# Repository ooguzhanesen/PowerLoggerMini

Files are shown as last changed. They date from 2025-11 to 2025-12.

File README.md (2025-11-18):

# Mini Power Logger

> **Hazırlayan:** Oğuzhan ESEN  
> **Proje Adı:** Mini Power Logger
> **Tarih:** 11 Kasım 2025
> **Versiyon:** v1.0
---

## İçindekiler

---

## 1. Giriş

Mini Power Logger, gerilim, akım ve güç tüketimini ölçmek, bu verileri hafızaya kaydetmek ve ekran üzerinden anlık olarak göstermek amacıyla geliştirilmiş bir izleme kartıdır.

Sistem, STM32F103 mikrodenetleyici tabanlıdır ve INA228 yüksek çözünürlüklü akım–voltaj sensörü sayesinde 20 bit çözünürlükte hassas ölçüm yapabilmektedir. Ayrıca  ölçülen veriler microSD karta kaydedebilmekte ve aynı zamanda OLED ekranda anlık değerler görülebilmektedir.

Mini Power Logger, arge projelerinde üzeritilen prototip ve cihazların güç tüketimini incelemek amacıyla tasarlanmıştır.

---

## 2. Tasarımın Amacı ve Kapsamı

Bu tasarımın temel amacı, enerji tüketimini düşük maliyetle, taşınabilir bir sistem üzerinden izleyebilmek ve ölçüm sonuçlarını kolayca kayıt altına almaktır.
Mini Power Logger, aşağıdaki fonksiyonları yerine getirir:

* 7–28 V DC aralığında güç girişi

* INA228 sensörü ile akım ve voltaj ölçümü (3 A'e kadar)

* microSD kart üzerinden veri kaydı

* 0.96” OLED ekran ile anlık ölçüm gösterimi

* USB Type-C bağlantısı (alternatif besleme ve veri aktarımı)

* 2 adet sıcaklık sensörü (cihazın çeşitli konumlarında sıcaklık ölçümü alabilmek için)

* 3 adet buton (menü kontrolü ve fonksiyon seçimi)

* Buzzer ile sesli uyarı

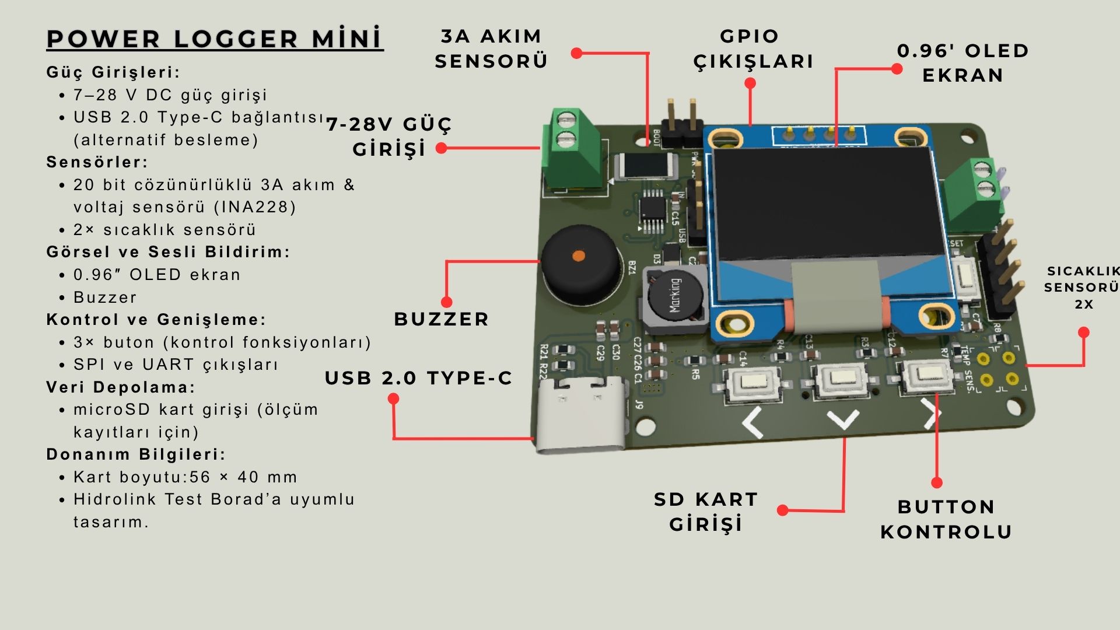
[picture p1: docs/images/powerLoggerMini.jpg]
Tanıtım Gorseli

---

## 3. Sistem Blok Diyagramı

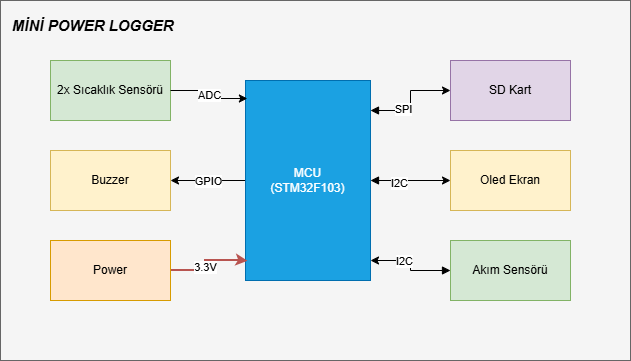
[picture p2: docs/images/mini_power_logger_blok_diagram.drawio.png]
Block Diagram


---

## 4. Şematik ve PCB
[Şematik tasarım için tıklayın.](docs/mini_power_logger.pdf)

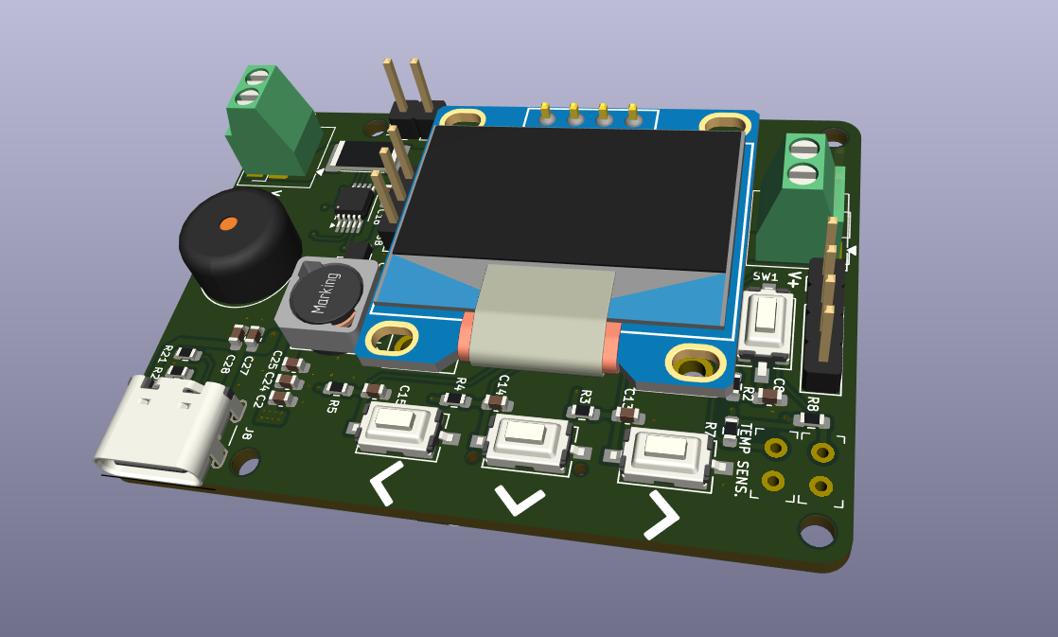
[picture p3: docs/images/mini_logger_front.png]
Mini Logger Front


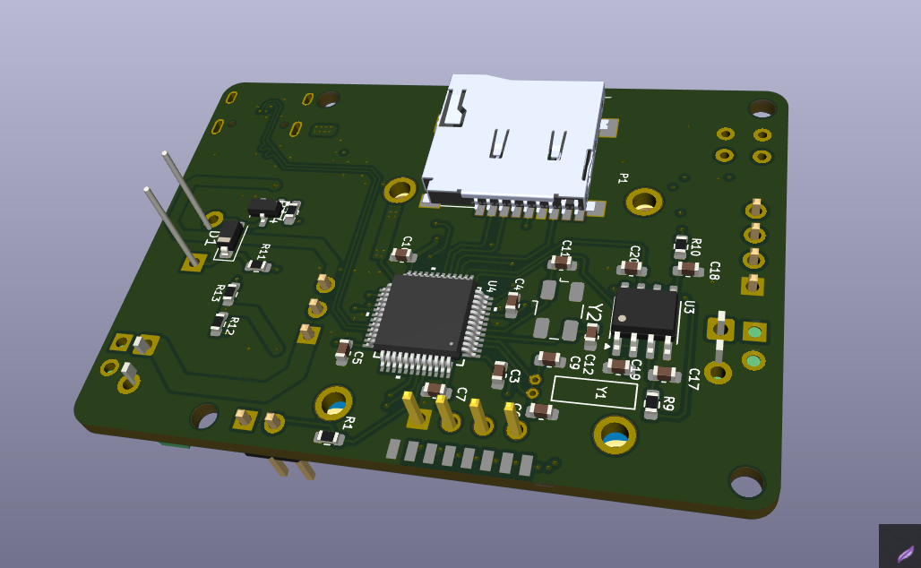
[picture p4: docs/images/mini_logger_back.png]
Mini Logger back


---

## 5. Test Notları

---

## 6. Geliştirme ve İyileştirme Önerileri

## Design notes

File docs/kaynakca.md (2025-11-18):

# Power Logger Mini Yazılım klavuzu 

> **Hazırlayan:** Oğuzhan ESEN  
> **Proje Adı:** STM32WL Nucleo Carrier Board  
> **Tarih:** 22 ekim 2025  
> **Versiyon:** v1.0

---

## 1. Giriş

Power Logger Mini porjesinde şu özelliklerin olması planlanmıştır.
- Akım ve voltaj bilgisinin edinilmesi (INA219,226,228).
- Oled ekran üzerinden gösterilmesi.
- Verileri sd karta kaydetmesi.
- Buton ile kayıt kontrolünün yapılması.
- Kaydın yapılırken tarih saat bilgisinin alınması.
- Hidrolink Test Boarda uyumlu olması.

Bu özellikleri karşılayabilmesi için komponet seçimi ve kaynakları verilmiştir.

### 1.1 Akım Voltaj bilgisinin karşılanması  için:
Bu bilginin karşılanması amacıyla INA219 , INA226 denenmiştir. INA226 bir ölçüde uygun oldugu görülmiş ama 16bit çözünürlük yerine 20 bit çözünürlüğün daha iyi olacagı
öngörüldüğü için INA228 kullanılmasına karar verilmiştir.
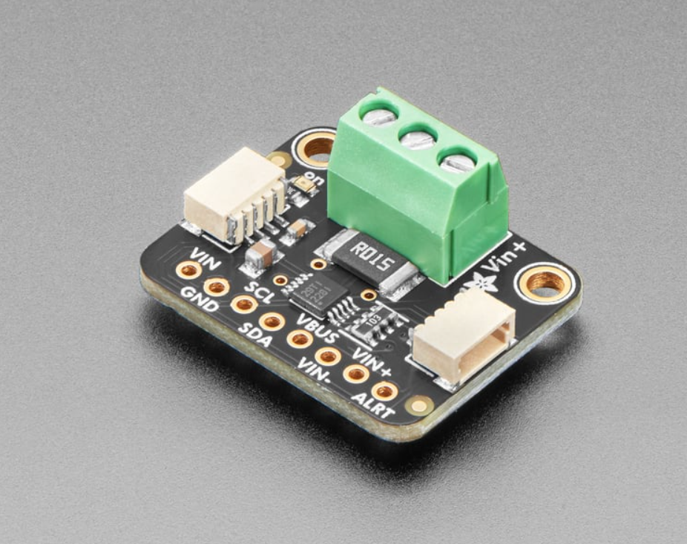
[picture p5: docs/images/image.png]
ına226


[INA228](https://www.ozdisan.com/p/diger-guc-yonetimi-entegreleri-281/texas-ina228aqdgsrq1-1086895)
[Arduino libi](https://github.com/RobTillaart/INA228)
[Sematik ve tasarım dosyaları](https://github.com/adafruit/Adafruit-INA228-PCB)

### 1.2 OLED Ekran:
Biglerin gösterimi için i2c ile çalışan oled ekran seçilmiştir.
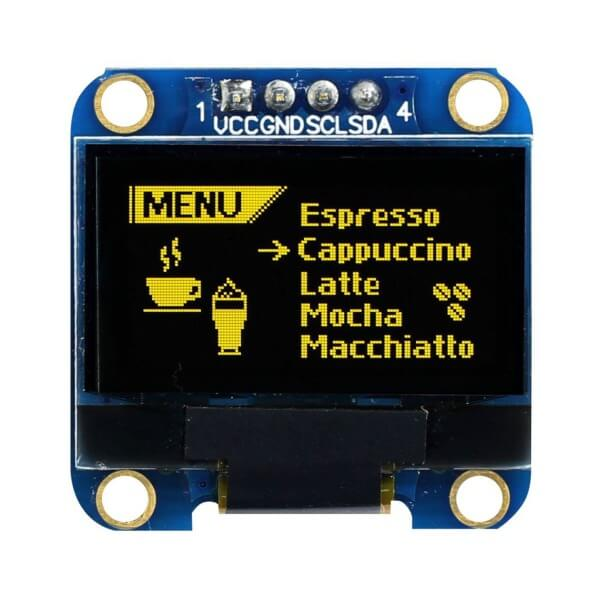
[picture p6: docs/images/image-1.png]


[Kullanılan ekranın datasheet'i](https://www.ozdisan.com/api/pdf/product/assets/WEA012864DLPP3N00003.pdf)

[Test için kullandığım git linki](https://github.com/RobertoBenjami/stm32_ssd1306_i2c_dma_hal/tree/master/Drivers)

### 1.3 SD Card:
SD kartta modülü kullanılmıştır ve sd karta kayıt spi üzerinden yapılmaktadır.
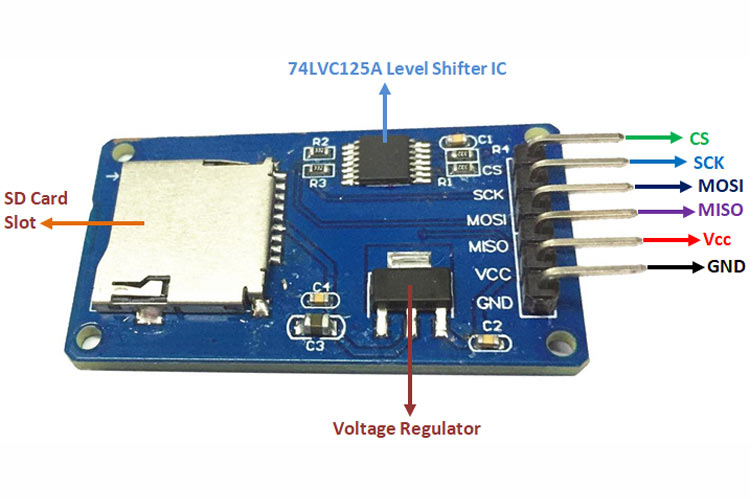
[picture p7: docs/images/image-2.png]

[SD kart için kullanılan kaynak](https://youtu.be/PBIm8BCnbyQ)
[SD kart için kullanılan git linki](https://github.com/PRTechTalk/STM32/tree/main/SD_Card_SPI_FatFs)

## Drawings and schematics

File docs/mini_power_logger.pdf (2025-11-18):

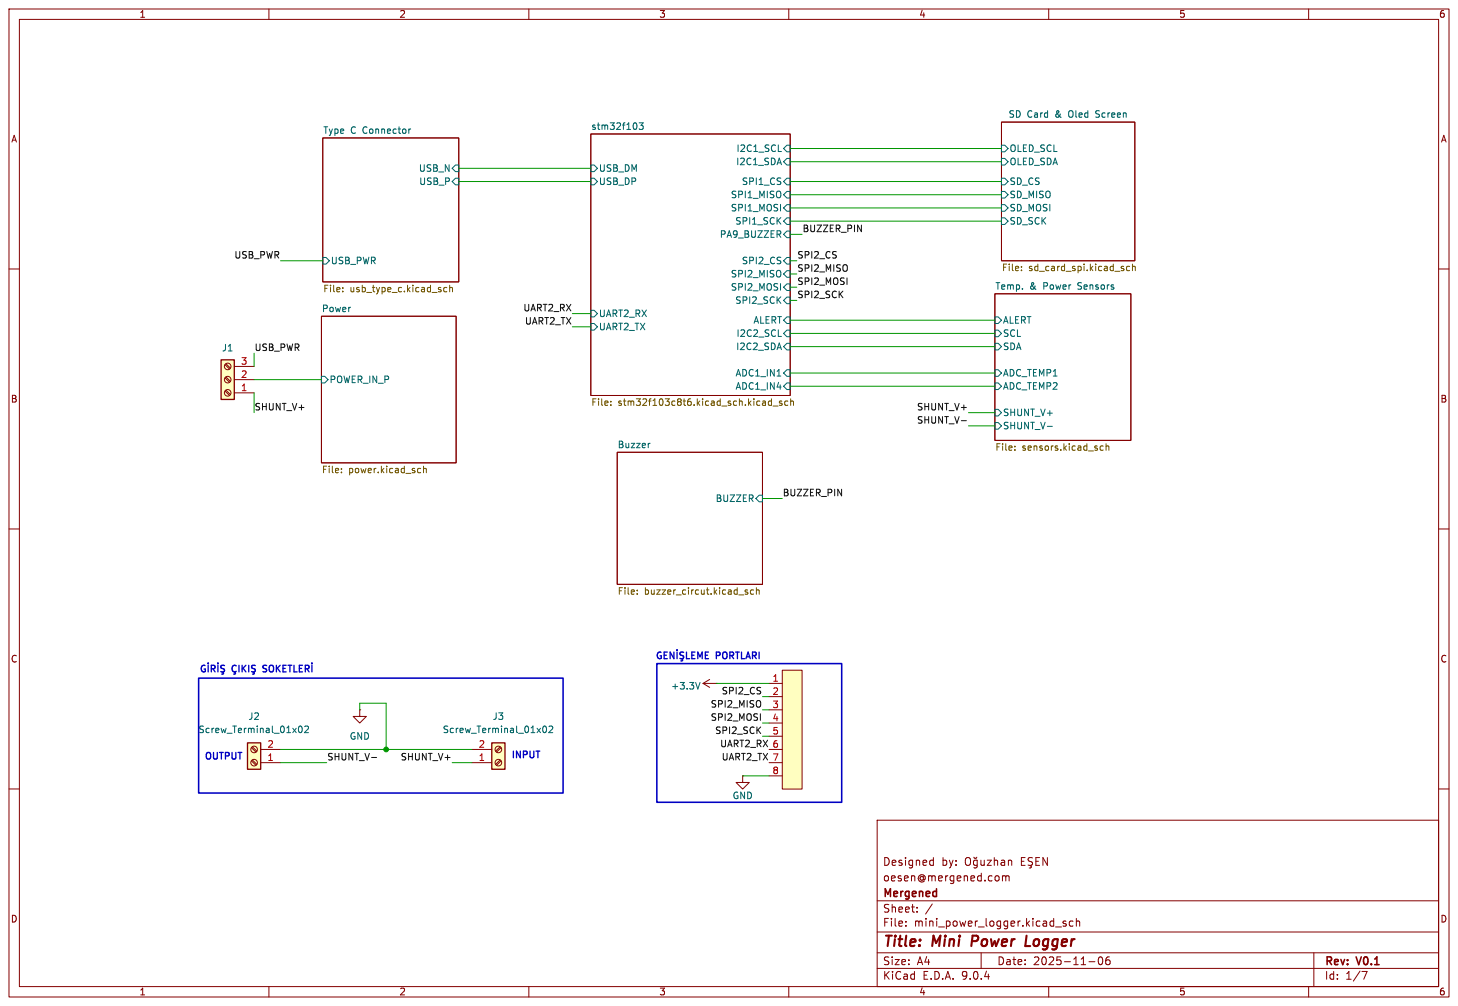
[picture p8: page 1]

SD Card & Oled Screen File: sd_card_spi.kicad_sch ALERT SCL SDA

ADC_TEMP1 ADC_TEMP2 SHUNT_V+ SHUNT_V- Temp. & Power Sensors File: sensors.kicad_sch

oesen@mergened.com
Id: 1/7 Title: Mini Power Logger File: mini_power_logger.kicad_sch Sheet: / Mergened

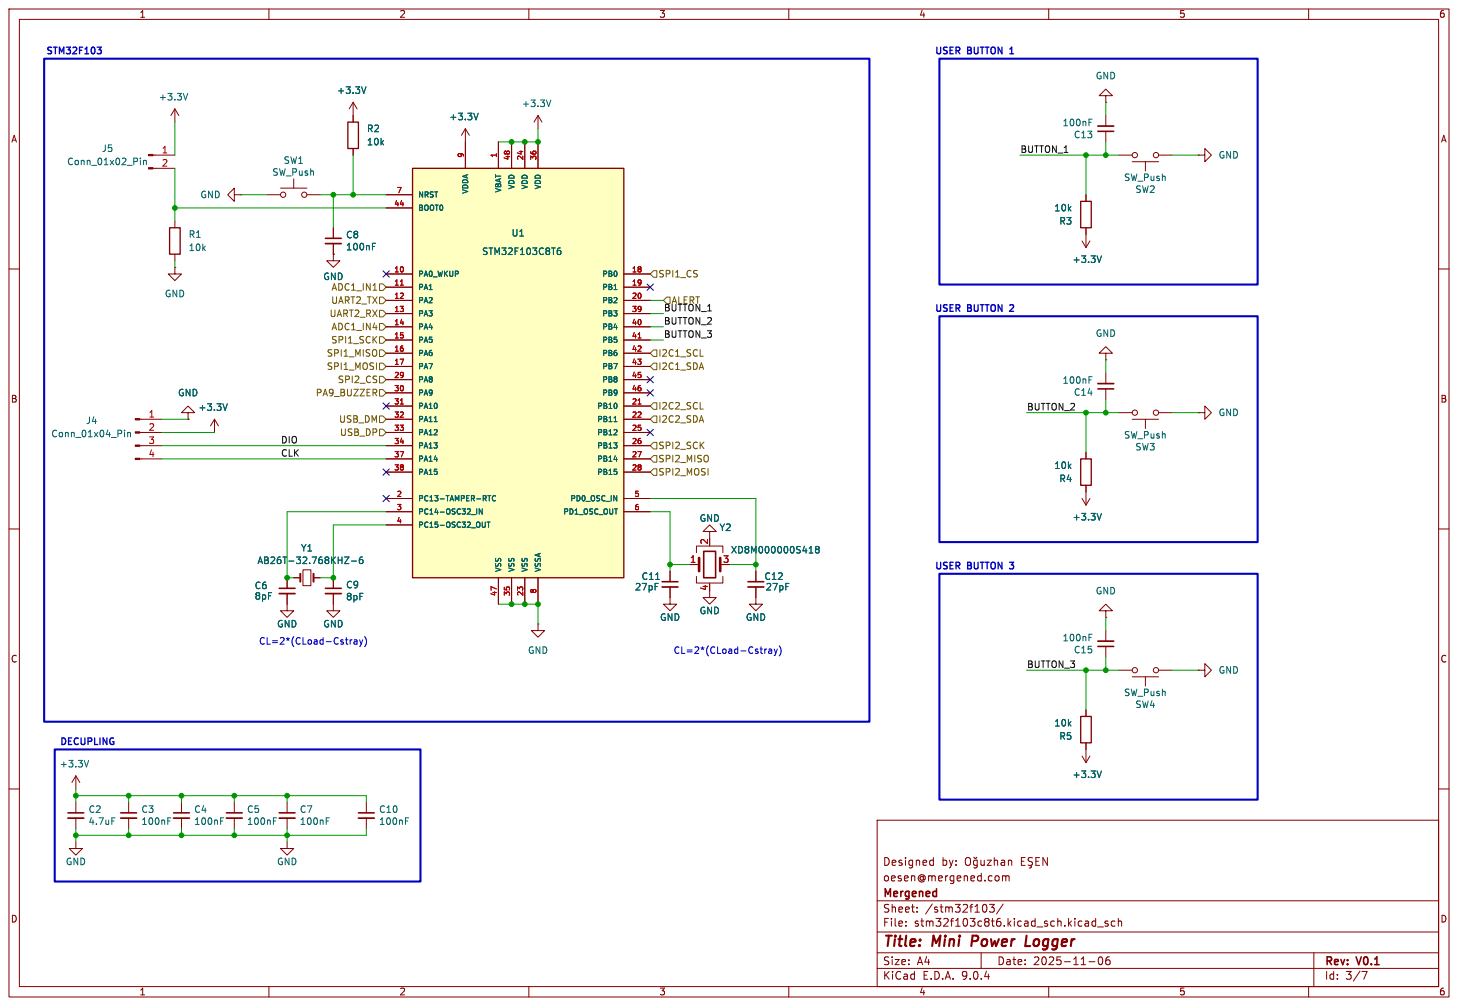
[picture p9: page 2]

1 VSS 47 VDD 48 VSS 35 VDD 24 VSS 23 VDD 36 VSSA

oesen@mergened.com
Id: 3/7 Title: Mini Power Logger File: stm32f103c8t6.kicad_sch.kicad_sch Sheet: /stm32f103/ Mergened

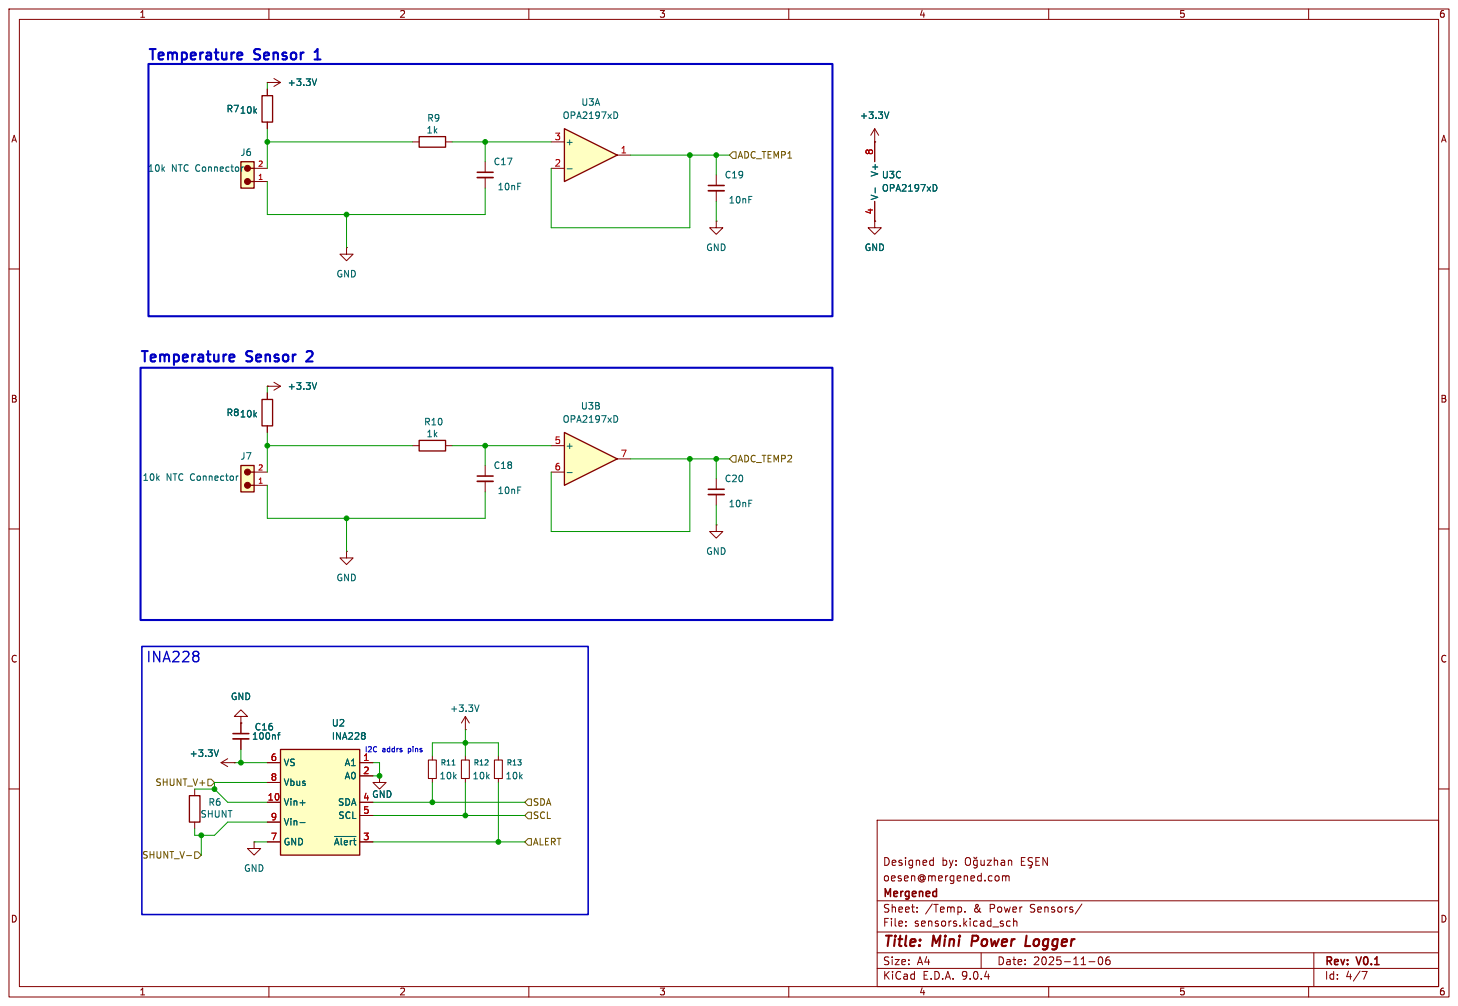
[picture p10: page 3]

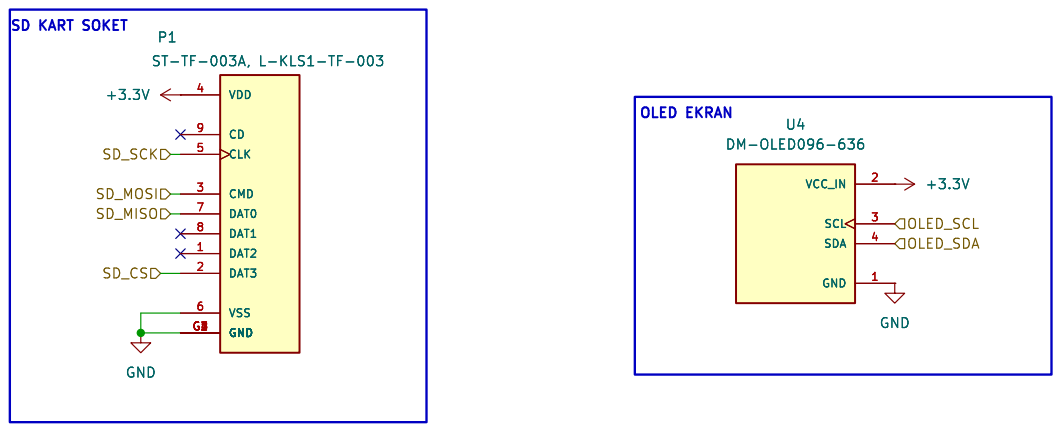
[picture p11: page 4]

oesen@mergened.com
Card | & Oled Screen/ Mergened Id: 4/7 Title: Mini Power Logger File: sd_card_spi.kicad_sch Sheet: /SD

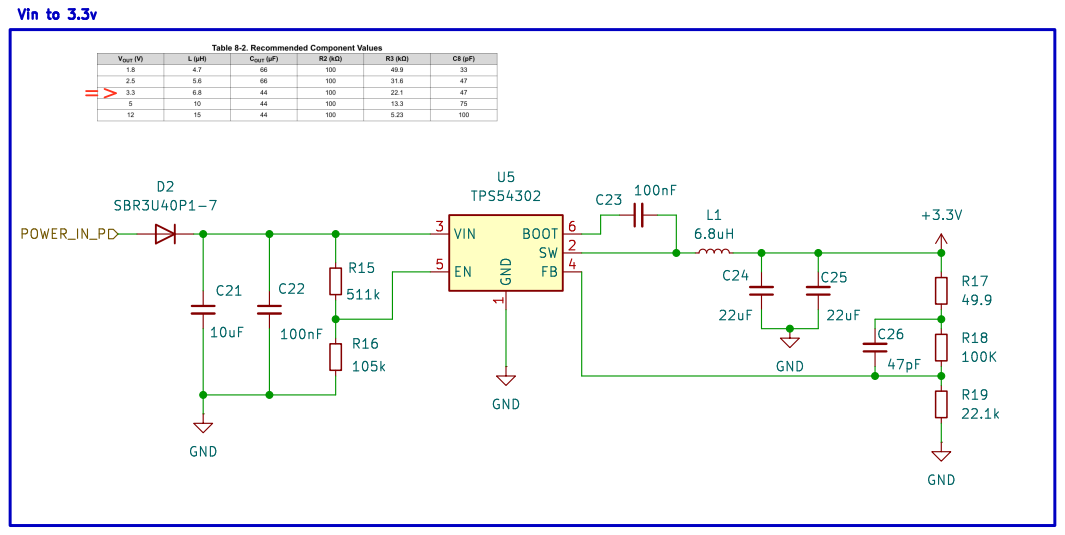
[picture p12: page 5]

oesen@mergened.com
Id: 5/7 Title: Mini Power Logger File: power.kicad_sch Sheet: /Power/ Mergened

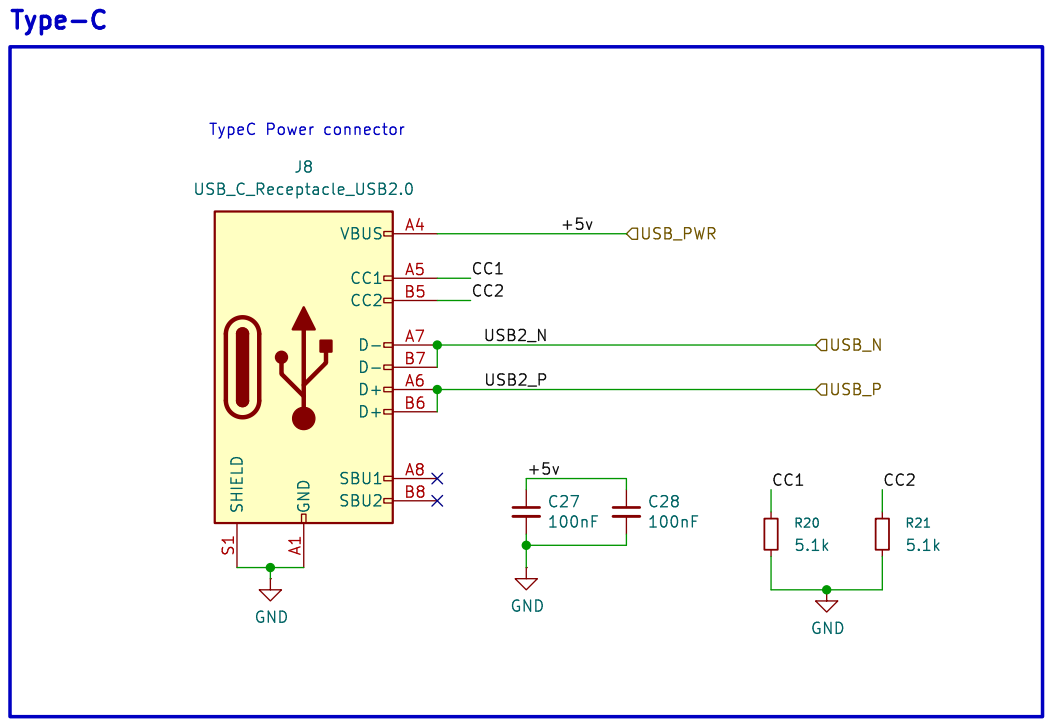
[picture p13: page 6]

oesen@mergened.com
Id: 6/7 Title: Mini Power Logger File: usb_type_c.kicad_sch Sheet: /Type C Connector/ Mergened

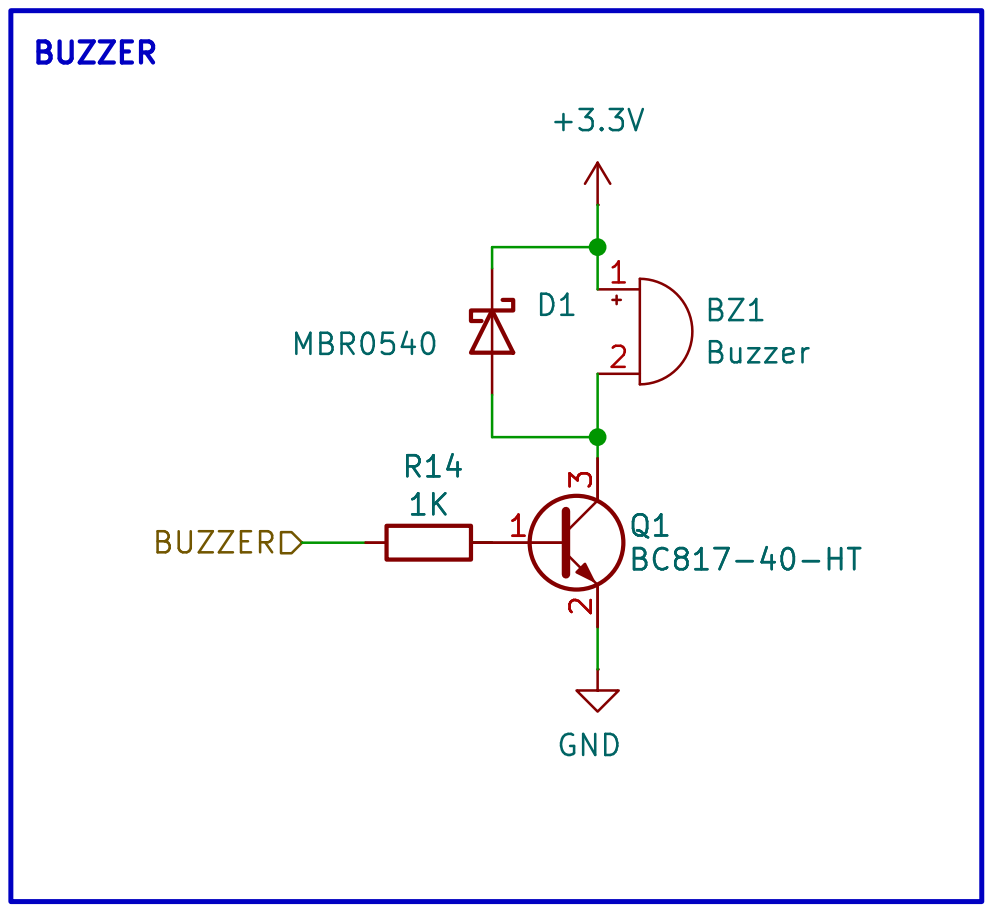
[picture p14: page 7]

oesen@mergened.com
Id: 7/7 Title: Mini Power Logger File: buzzer_circut.kicad_sch Sheet: /Buzzer/ Mergened

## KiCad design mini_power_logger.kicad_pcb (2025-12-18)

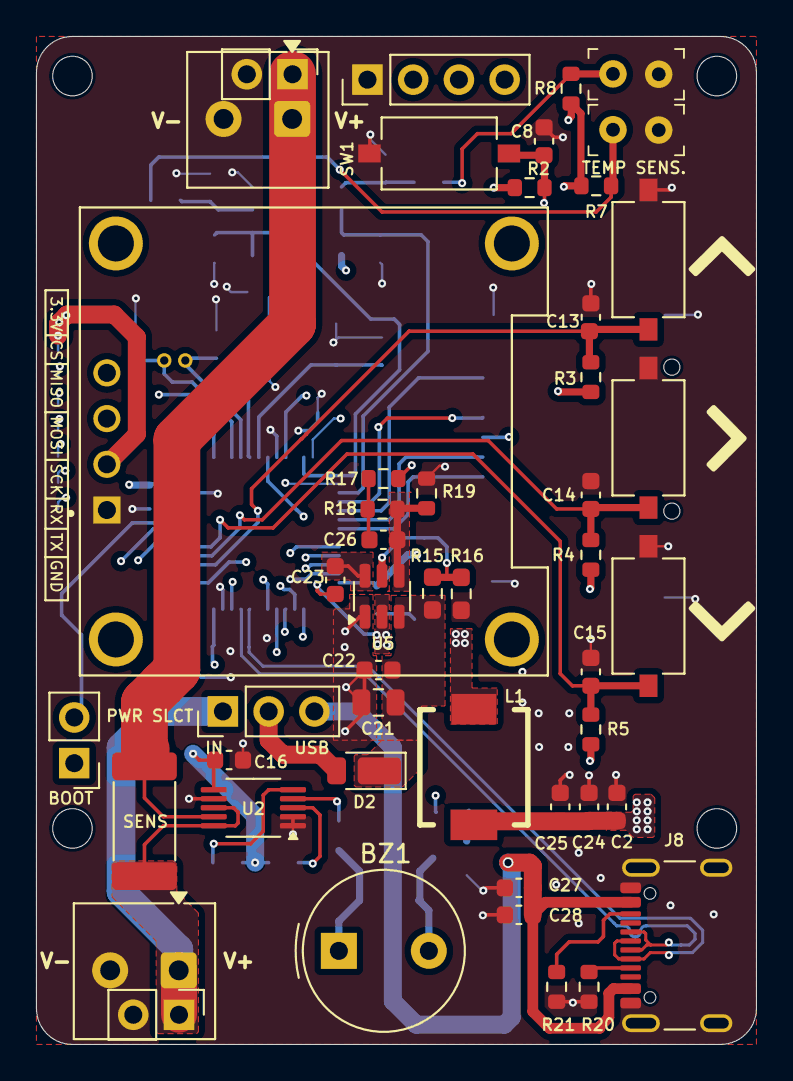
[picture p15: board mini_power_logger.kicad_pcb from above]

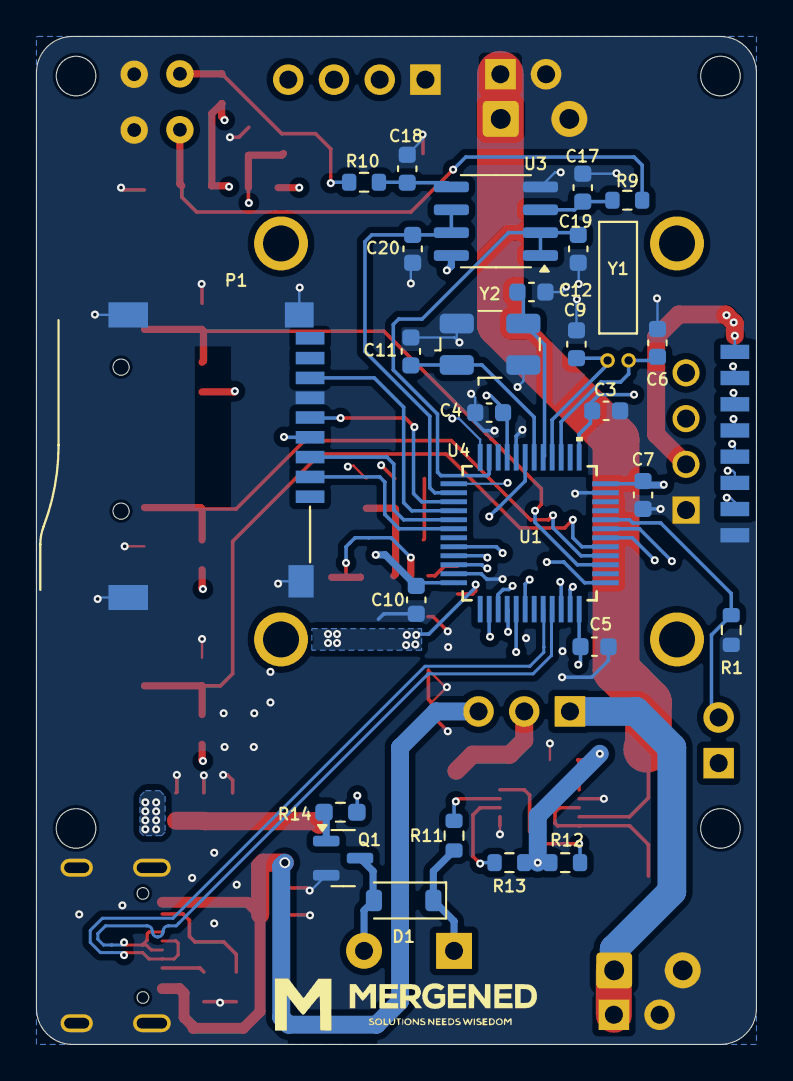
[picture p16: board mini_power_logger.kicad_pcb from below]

Board: 4 copper layers, 40.0 x 56.0 mm, 76 parts (28 on the bottom side), 51 nets.

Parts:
BZ1: Buzzer; Buzzer_TDK_PS1240P02BT_D12.2mm_H6.5mm
C1: Connector_PinHeader_2.54mm; PinHeader_1x08_P2.54mm_Vertical_SMD_Pin1Right
C2: 4.7uF; C_0603_1608Metric
C3, C4, C5, C7, C8, C10, C13, C14, C15, C22, C23, C27, C28: 100nF; C_0603_1608Metric
C6, C9: 8pF; C_0603_1608Metric
C11, C12: 27pF; C_0603_1608Metric
C16: 100nf; C_0603_1608Metric
C17, C18, C19, C20: 10nF; C_0603_1608Metric
C21: 10uF; C_0805_2012Metric
C24, C25: 22uF; C_0603_1608Metric
C26: 47pF; C_0603_1608Metric
D1: MBR0540; D_SOD-123
D2: SBR3U40P1-7; D_PowerDI-123
J1, J1#2: 691322310002; PinHeader_1x02_P2.54mm_Vertical
J1#3: Screw_Terminal_01x03; PinHeader_1x03_P2.54mm_Vertical
J2, J3: Screw_Terminal_01x02; TerminalBlock_Phoenix_MKDS-1-2-3.81_1x02_P3.81mm_Horizontal
J4: Conn_01x04_Pin; PinHeader_1x04_P2.54mm_Vertical
J5: Conn_01x02_Pin; PinHeader_1x02_P2.54mm_Vertical
J6, J7: 10k NTC Connector; PinHeader_1x2_P2.54mm
J8: USB_C_Receptacle_USB2.0; USB_C_Receptacle_GCT_USB4105-xx-A_16P_TopMnt_Horizontal
L1: 6.8uH; INDC6060X300
P1: ST-TF-003A, L-KLS1-TF-003; sdcardsoket
Q1: BC817-40-HT; SOT-23
R1, R2, R3, R4, R5, R7, R8, R11, R12, R13: 10k; R_0603_1608Metric
R6: SHUNT; R_2512_6332Metric_Pad1.40x3.35mm_HandSolder
R9, R10: 1k; R_0603_1608Metric
R14: 1K; R_0603_1608Metric_Pad0.98x0.95mm_HandSolder
R15: 511k; R_0603_1608Metric_Pad0.98x0.95mm_HandSolder
R16: 105k; R_0603_1608Metric_Pad0.98x0.95mm_HandSolder
R17: 49.9; R_0603_1608Metric
R18: 100K; R_0603_1608Metric
R19: 22.1k; R_0603_1608Metric
R20, R21: 5.1k; R_0603_1608Metric
SW1, SW2, SW3, SW4: SW_Push; SW_Tactile_SPST_NO_Straight_CK_PTS636Sx25SMTRLFS
U1: STM32F103C8T6; LQFP48_STM
U2: INA228; VSSOP-10_3x3mm_P0.5mm
U3: OPA2197xD; SOIC-8_3.9x4.9mm_P1.27mm
U4: DM-OLED096-636; MODULE_DM-OLED096-636
U5: TPS54302; SOT-23-6
Y1: AB26T-32.768KHZ-6; XTAL_AB26T-32.768KHZ-6
Y2: XD8M000000S418; Crystal_SMD_EuroQuartz_MJ-4Pin_5.0x3.2mm

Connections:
+3.3V: BZ1.1 (+), C1.1, C2.1, C3.1, C4.1, C5.1, C7.1, C10.1, C16.2, C24.2, C25.2, D1.1 (K), J4.2, J5.1, L1.2, P1.4 (VDD), R2.1, R3.1, R4.1, R5.1, R7.2, R8.2, R11.1, R12.1, R13.1, R17.1, U1.1 (VBAT), U1.9 (VDDA), U1.24 (VDD), U1.36 (VDD), U1.48 (VDD), U2.6 (VS), U3.8 (V+), U4.2 (VCC_IN)
/BUZZER_PIN: R14.1, U1.30 (PA9)
/Power/POWER_IN_P: D2.2 (A), J1#3.2
/SD Card & Oled Screen/OLED_SCL: U1.42 (PB6), U4.3 (SCL)
/SD Card & Oled Screen/OLED_SDA: U1.43 (PB7), U4.4 (SDA)
/SD Card & Oled Screen/SD_CS: P1.2 (DAT3), U1.18 (PB0)
/SD Card & Oled Screen/SD_MISO: P1.7 (DAT0), U1.16 (PA6)
/SD Card & Oled Screen/SD_MOSI: P1.3 (CMD), U1.17 (PA7)
/SD Card & Oled Screen/SD_SCK: P1.5 (CLK), U1.15 (PA5)
/SHUNT_V+: J1.1, J1#3.1, J3.1, R6.1, U2.8 (Vbus), U2.10 (Vin+)
/SHUNT_V-: J1#2.1, J2.1, R6.2, U2.9 (Vin-)
/SPI2_CS: C1.2, U1.29 (PA8)
/SPI2_MISO: C1.3, U1.27 (PB14)
/SPI2_MOSI: C1.4, U1.28 (PB15)
/SPI2_SCK: C1.5, U1.26 (PB13)
/Temp. & Power Sensors/ADC_TEMP1: C19.1, U1.11 (PA1), U3.1, U3.2 (-)
/Temp. & Power Sensors/ADC_TEMP2: C20.1, U1.14 (PA4), U3.6 (-), U3.7
/Temp. & Power Sensors/ALERT: R13.2, U1.20 (PB2), U2.3 (~Alert)
/Temp. & Power Sensors/SCL: R12.2, U1.21 (PB10), U2.5 (SCL)
/Temp. & Power Sensors/SDA: R11.2, U1.22 (PB11), U2.4 (SDA)
/Type C Connector/CC1: J8.A5 (CC1), R20.1
/Type C Connector/CC2: J8.B5 (CC2), R21.1
/Type C Connector/USB2_N: J8.A7 (D-), J8.B7 (D-), U1.32 (PA11)
/Type C Connector/USB2_P: J8.A6 (D+), J8.B6 (D+), U1.33 (PA12)
/UART2_RX: C1.6, U1.13 (PA3)
/UART2_TX: C1.7, U1.12 (PA2)
/USB_PWR: C27.1, C28.1, J1#3.3, J8.A4 (VBUS), J8.A9 (VBUS), J8.B4 (VBUS), J8.B9 (VBUS)
/stm32f103/BUTTON_1: C13.1, R3.2, SW2.2, U1.39 (PB3)
/stm32f103/BUTTON_2: C14.1, R4.2, SW3.2, U1.40 (PB4)
/stm32f103/BUTTON_3: C15.1, R5.2, SW4.2, U1.41 (PB5)
/stm32f103/CLK: J4.4, U1.37 (PA14)
/stm32f103/DIO: J4.3, U1.34 (PA13)
GND: C1.8, C2.2, C3.2, C4.2, C5.2, C6.2, C7.2, C8.2, C9.2, C10.2, C11.2, C12.2, C13.2, C14.2, C15.2, C16.1, C17.2, C18.2, C19.2, C20.2, C21.2, C22.2, C24.1, C25.1, C27.2, C28.2, J1.2, J1#2.2, J2.2, J3.2, J4.1, J6.1, J7.1, J8.A1 (GND), J8.A12 (GND), J8.B1 (GND), J8.B12 (GND), J8.S1 (SHIELD), P1.6 (VSS), P1.G1 (GND), P1.G2 (GND), P1.G3 (GND), P1.G4 (GND), Q1.2 (E), R1.2, R16.2, R19.2, R20.2, R21.2, SW1.1, SW2.1, SW3.1, SW4.1, U1.8 (VSSA), U1.23 (VSS), U1.35 (VSS), U1.47 (VSS), U2.1 (A1), U2.2 (A0), U2.7 (GND), U3.4 (V-), U4.1 (GND), U5.1 (GND), Y2.2, Y2.4
unnamed: BZ1.2 (-), D1.2 (A), Q1.3 (C)
unnamed: C26.2, R17.2, R18.1
unnamed: C21.1, C22.1, D2.1 (K), R15.1, U5.3 (VIN)
unnamed: J5.2, R1.1, U1.44 (BOOT0)
unnamed: J6.2, R7.1, R9.1
unnamed: J7.2, R8.1, R10.1
unnamed: Q1.1 (B), R14.2
unnamed: C8.1, R2.2, SW1.2, U1.7 (NRST)
unnamed: C6.1, U1.3 (PC14-OSC32_IN), Y1.1
unnamed: C9.1, U1.4 (PC15-OSC32_OUT), Y1.2
unnamed: C12.1, U1.5 (PD0_OSC_IN), Y2.3
unnamed: C11.1, U1.6 (PD1_OSC_OUT), Y2.1
unnamed: C17.1, R9.2, U3.3 (+)
unnamed: C18.1, R10.2, U3.5 (+)
unnamed: C23.1, U5.6 (BOOT)
unnamed: R15.2, R16.1, U5.5 (EN)
unnamed: C26.1, R18.2, R19.1, U5.4 (FB)
unnamed: C23.2, L1.1, U5.2 (SW)

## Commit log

2025-11-18 final porject.
    [buzzer_circut.kicad_sch, mini_power_logger.kicad_pcb, mini_power_logger.kicad_sch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]
2025-12-18 final design.
    [buzzer_circut.kicad_sch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]
